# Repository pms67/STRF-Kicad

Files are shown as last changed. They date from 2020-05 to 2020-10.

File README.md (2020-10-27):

# STRF 2.4GHz RF-to-USB Dongle
STM32L4-based RF-to-USB dongle using a low-power NRF24 2.4GHz transceiver.

4-layer PCB designed in KiCad. Video: [https://www.youtube.com/watch?v=14_jh3nLSsU](https://www.youtube.com/watch?v=14_jh3nLSsU)

You can order this board (incl. SMT assembly) at [https://www.jlcpcb.com](https://www.jlcpcb.com). Gerber and assembly files are in the relevant repo folders.

STRF

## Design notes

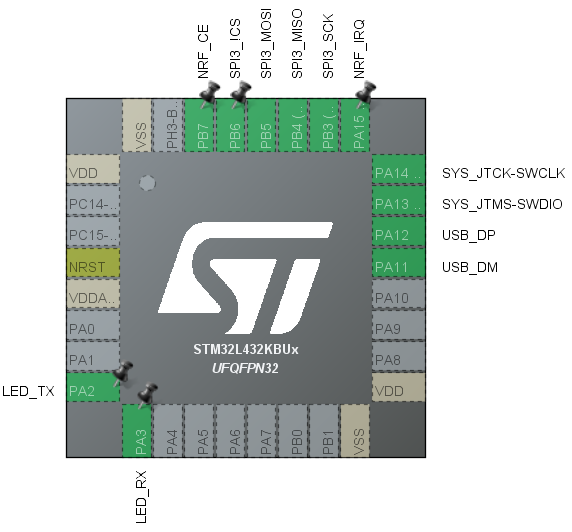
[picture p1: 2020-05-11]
misc/STM32L4 Pinout.PNG

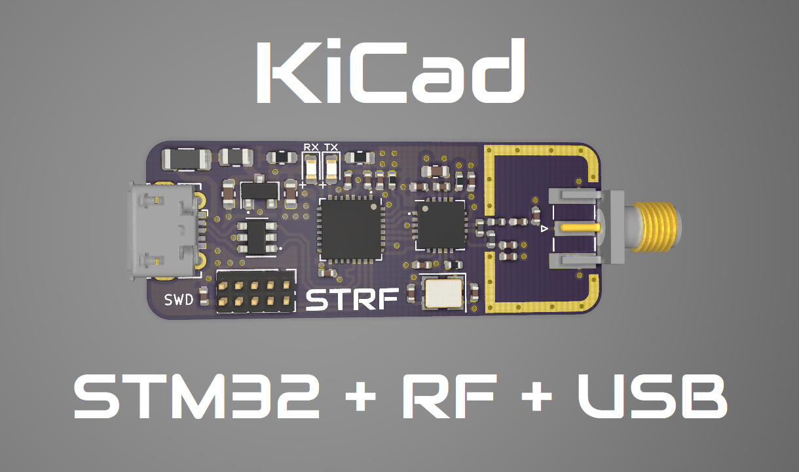
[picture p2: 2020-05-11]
misc/STRF-3D-Screenshot.png

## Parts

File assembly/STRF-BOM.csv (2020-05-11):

Designator | Quantity | Value | Footprint | LCSC Part #
C1, C2, C8, | 3 | 10u | 0603 | C19702
C3, C5, C6, C7, | 4 | 100n | 0402 | C1525
C4, | 1 | 1u | 0402 | C52923
C9, C10, C11, | 3 | 10n | 0402 | C15195
C12, | 1 | 33n | 0402 | C1585
C13, C14, | 2 | 12p | 0402 | C1547
C15, | 1 | 1p5 | 0402 | C1552
C16, | 1 | 1p | 0402 | C1550
C17, | 1 | 2n2 | 0402 | C1531
C18, | 1 | 4p7 | 0402 | C1569
D1, | 1 | GR | 0603 | C72043
D2, | 1 | YE | 0603 | C72038
F1, | 1 | 100mA | 1206
FB1, | 1 | 100 @ 100MHz | 0805 | C1015
L1, | 1 | 3n9 | 0402 | C14033
L2, | 1 | 8n2 | 0402 | C16208
L3, | 1 | 2n7 | 0402 | C27123
R1, | 1 | 10k | 0402 | C25744
R2, R3, | 2 | 2k2 | 0603 | C4190
R4, | 1 | 22k | 0402 | C25768
R5, | 1 | 1M | 0402 | C26083
U1, | 1 | XC6206P332MR | SOT-23 | C5446
U2, | 1 | USBLC6-2SC6 | SOT-23-6 | C7519
U3, | 1 | STM32L432KBU6 | UFQFPN-32_EP_5.0x5.0x0.5P | C94784
U4, | 1 | nRF24L01P | QFN-20_EP_4.0x4.0x0.5P | C8791
Y1, | 1 | 16MHz | SMD-3225_4P | C13738

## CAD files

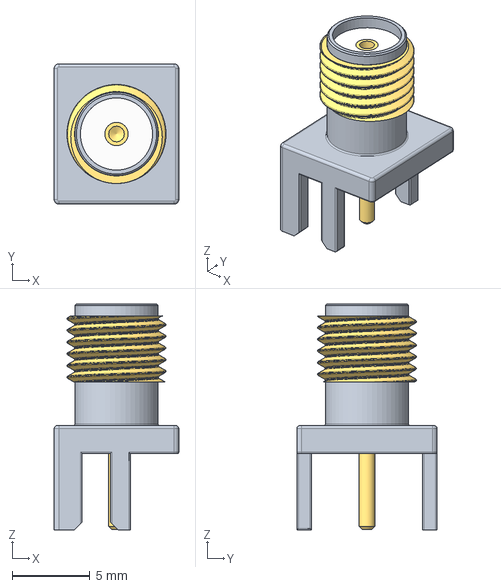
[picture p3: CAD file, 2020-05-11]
misc/SMA-20.stp
8.00 x 9.00 x 14.5 mm

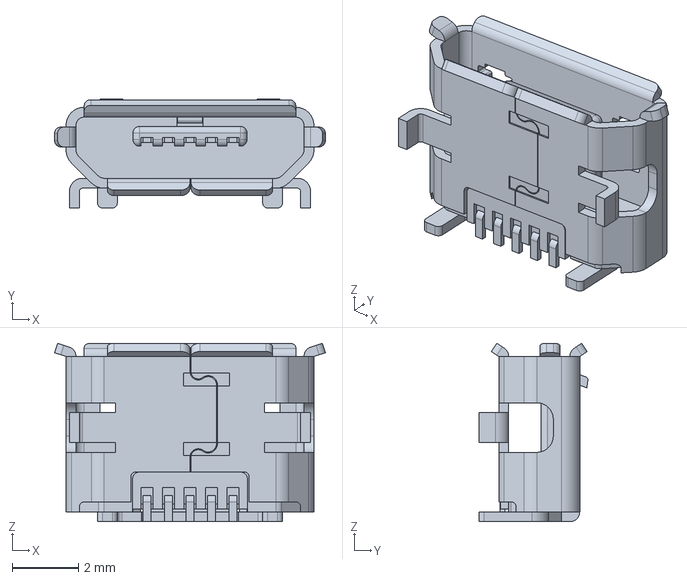
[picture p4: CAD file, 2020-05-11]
misc/1050170001.stp
8.20 x 3.30 x 5.40 mm

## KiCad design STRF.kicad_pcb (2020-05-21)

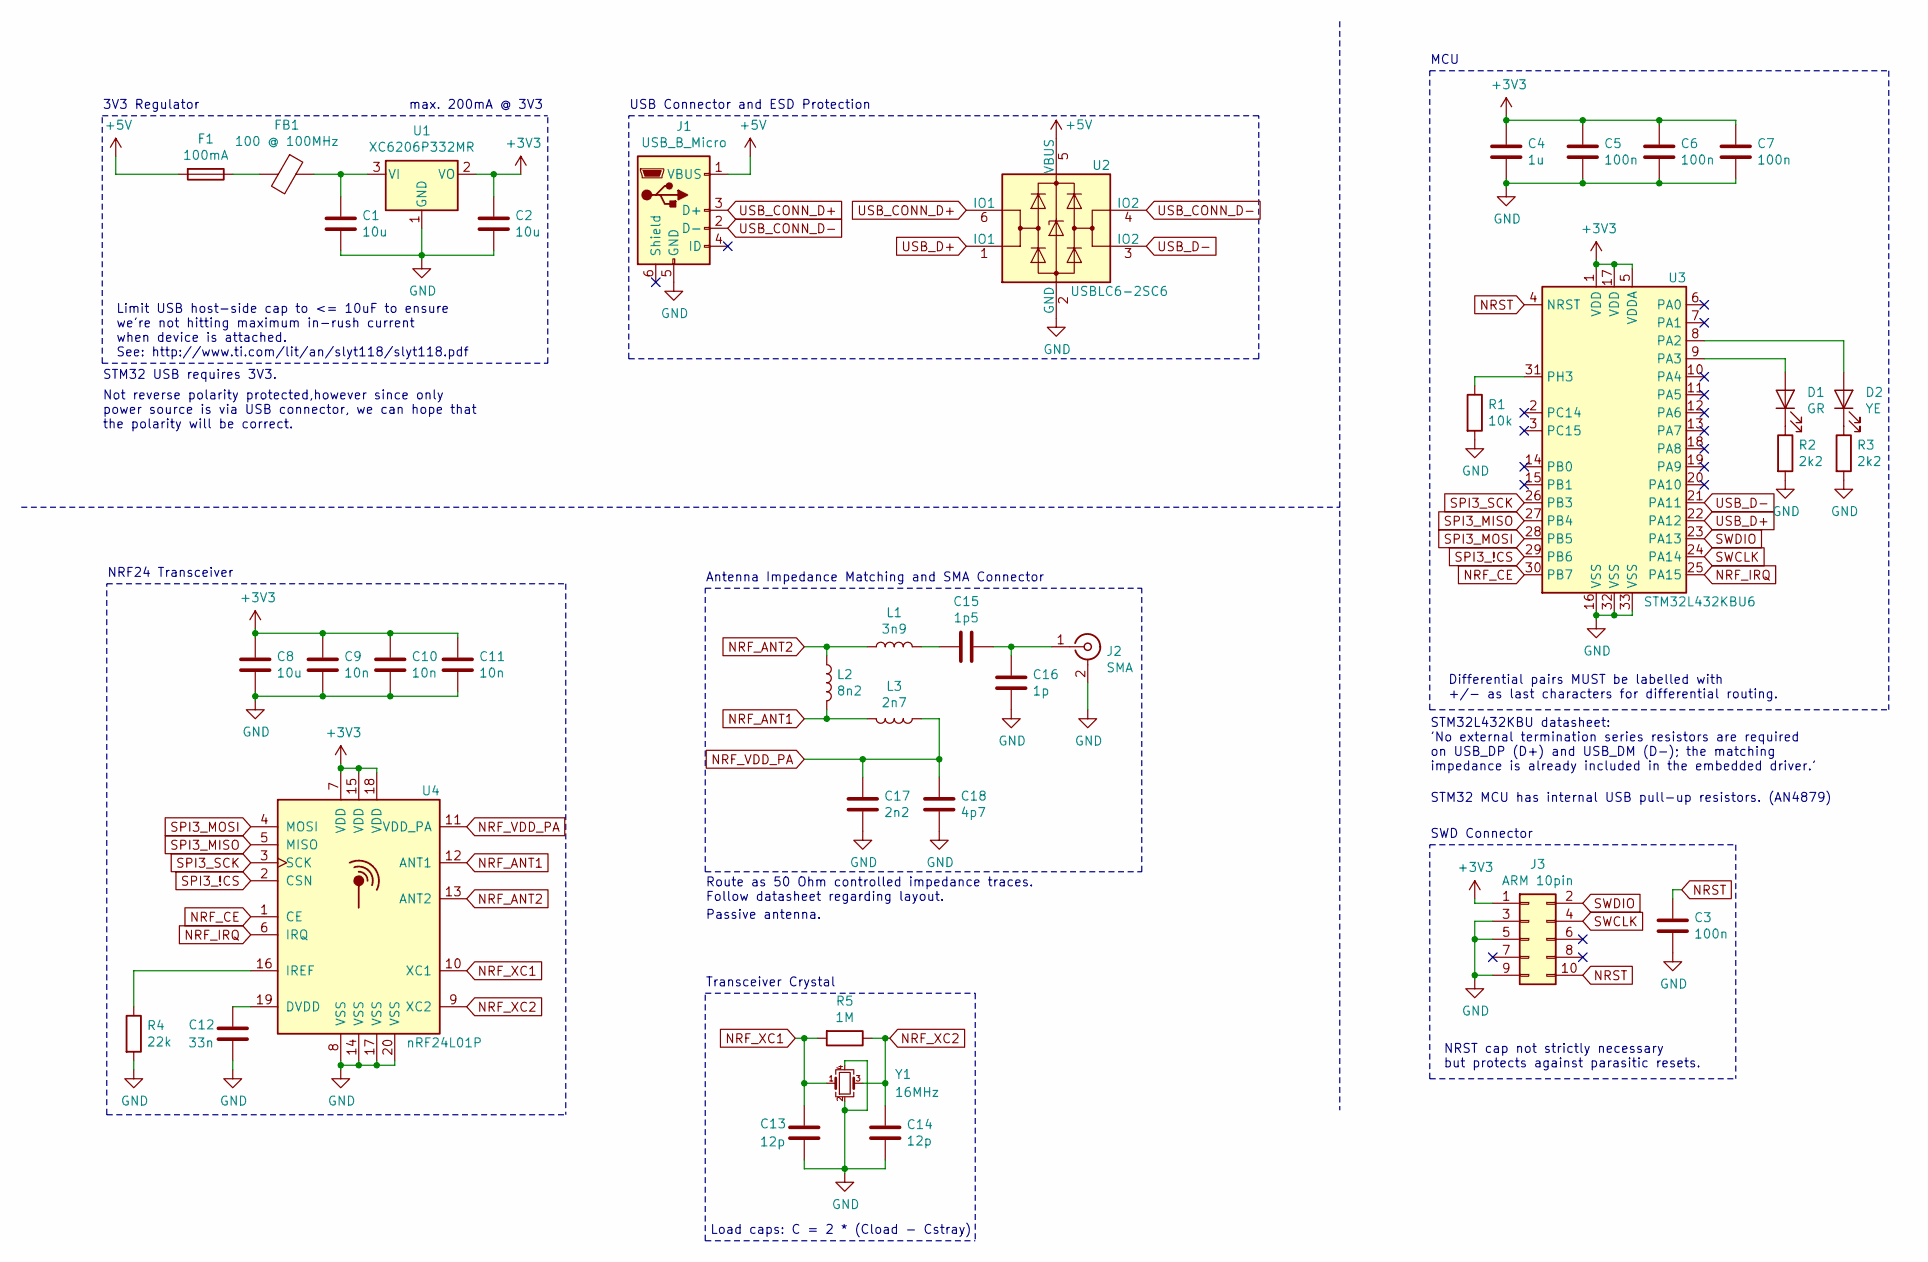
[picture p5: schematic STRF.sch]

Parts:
C1, C2, C8: 10u; C_0603_1608Metric
C3, C5, C6, C7: 100n; C_0402_1005Metric
C4: 1u; C_0402_1005Metric
C9, C10, C11: 10n; C_0402_1005Metric
C12: 33n; C_0402_1005Metric
C13, C14: 12p; C_0402_1005Metric
C15: 1p5; C_0402_1005Metric
C16: 1p; C_0402_1005Metric
C17: 2n2; C_0402_1005Metric
C18: 4p7; C_0402_1005Metric
D1: GR; LED_0603_1608Metric
D2: YE; LED_0603_1608Metric
F1: 100mA; Fuse_1206_3216Metric
FB1: 100 @ 100MHz; L_0805_2012Metric
J1: USB_B_Micro; 101181930001LF
J2: SMA; SMA_Samtec_SMA-J-P-X-ST-EM1_EdgeMount
J3: ARM 10pin; PinHeader_2x05_P1.27mm_Vertical
L1: 3n9; L_0402_1005Metric
L2: 8n2; L_0402_1005Metric
L3: 2n7; L_0402_1005Metric
R1: 10k; R_0402_1005Metric
R2, R3: 2k2; R_0603_1608Metric
R4: 22k; R_0402_1005Metric
R5: 1M; R_0402_1005Metric
U1: XC6206P332MR; SOT-23
U2: USBLC6-2SC6; SOT-23-6
U3: STM32L432KBU6; QFN-32-1EP_5x5mm_P0.5mm_EP3.45x3.45mm
U4: nRF24L01P; QFN-20-1EP_4x4mm_P0.5mm_EP2.5x2.5mm
Y1: 16MHz; Crystal_SMD_3225-4Pin_3.2x2.5mm

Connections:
+3V3: C2.1, C4.1, C5.1, C6.1, C7.1, C8.1, C9.1, C10.1, C11.1, J3.1, U1.2 (VO), U3.1 (VDD), U3.5 (VDDA), U3.17 (VDD), U4.7 (VDD), U4.15 (VDD), U4.18 (VDD)
+5V: F1.2, J1.1 (VBUS), U2.5 (VBUS)
GND: C1.2, C2.2, C3.2, C4.2, C5.2, C6.2, C7.2, C8.2, C9.2, C10.2, C11.2, C12.2, C13.2, C14.2, C16.1, C17.1, C18.1, J1.5 (GND), J2.2 (Ext), J3.3, J3.5, J3.9, R1.2, R2.2, R3.2, R4.2, U1.1 (GND), U2.2 (GND), U3.16 (VSS), U3.32 (VSS), U3.33 (VSS), U4.8 (VSS), U4.14 (VSS), U4.17 (VSS), U4.20 (VSS), U4.21, Y1.2, Y1.4
NRF_ANT1: L2.2, L3.2, U4.12 (ANT1)
NRF_ANT2: L1.1, L2.1, U4.13 (ANT2)
NRF_CE: U3.30 (PB7), U4.1 (CE)
NRF_IRQ: U3.25 (PA15), U4.6 (IRQ)
NRF_VDD_PA: C17.2, C18.2, L3.1, U4.11 (VDD_PA)
NRF_XC1: C13.1, R5.2, U4.10 (XC1), Y1.1
NRF_XC2: C14.1, R5.1, U4.9 (XC2), Y1.3
NRST: C3.1, J3.10, U3.4 (NRST)
unnamed: C1.1, FB1.1, U1.3 (VI)
unnamed: C12.1, U4.19 (DVDD)
unnamed: C15.1, C16.2, J2.1 (In)
unnamed: C15.2, L1.2
unnamed: D1.1 (K), R2.1
unnamed: D1.2 (A), U3.9 (PA3)
unnamed: D2.1 (K), R3.1
unnamed: D2.2 (A), U3.8 (PA2)
unnamed: F1.1, FB1.2
unnamed: R1.1, U3.31 (PH3)
unnamed: R4.1, U4.16 (IREF)
SPI3_!CS: U3.29 (PB6), U4.2 (CSN)
SPI3_MISO: U3.27 (PB4), U4.5 (MISO)
SPI3_MOSI: U3.28 (PB5), U4.4 (MOSI)
SPI3_SCK: U3.26 (PB3), U4.3 (SCK)
SWCLK: J3.4, U3.24 (PA14)
SWDIO: J3.2, U3.23 (PA13)
USB_CONN_D+: J1.3 (D+), U2.6 (IO1)
USB_CONN_D-: J1.2 (D-), U2.4 (IO2)
USB_D+: U2.1 (IO1), U3.22 (PA12)
USB_D-: U2.3 (IO2), U3.21 (PA11)

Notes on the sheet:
Limit USB host-side cap to <= 10uF to ensure we're not hitting maximum in-rush current when device is attached. See: http://www.ti.com/lit/an/slyt118/slyt118.pdf
NRST cap not strictly necessary but protects against parasitic resets.
Differential pairs MUST be labelled with +/- as last characters for differential routing.
3V3 Regulator
MCU
SWD Connector
STM32 MCU has internal USB pull-up resistors. (AN4879)
STM32 USB requires 3V3.
STM32L432KBU datasheet: 'No external termination series resistors are required on USB_DP (D+) and USB_DM (D-); the matching impedance is already included in the embedded driver.'
Not reverse polarity protected,however since only power source is via USB connector, we can hope that the polarity will be correct.
Load caps: C = 2 * (Cload - Cstray)
NRF24 Transceiver
Transceiver Crystal
USB Connector and ESD Protection
Antenna Impedance Matching and SMA Connector
Route as 50 Ohm controlled impedance traces. Follow datasheet regarding layout.
Passive antenna.
max. 200mA @ 3V3

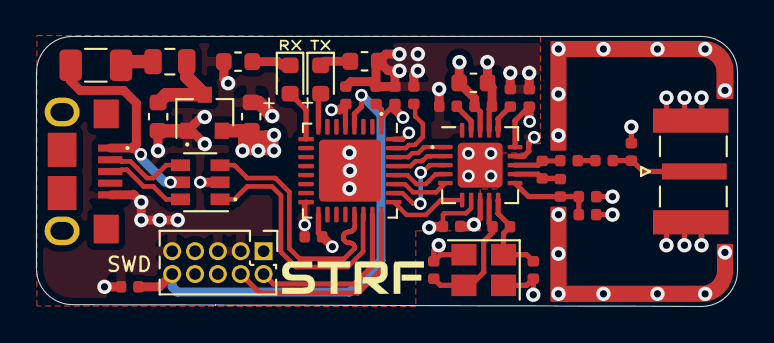
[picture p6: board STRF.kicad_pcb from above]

Board: 4 copper layers, 39.0 x 15.0 mm, 38 parts (0 on the bottom side), 32 nets.

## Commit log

2020-05-11 Initial commit.
    [1050170001.stp, SMA-20.stp, STRF-BOM.csv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]
2020-05-13 Fixed IREF resistor to pull-down.
    [STRF-BOM-Panel.csv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]
2020-05-14 Shifted SWD header further away from USB to gain space for connector.
    [STRF-B_Cu.gbr, STRF-B_Mask.gbr, STRF-B_Paste.gbr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]
2020-05-15 Updated Gerbers.
    [STRF-BOM-Panel.csv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]
2020-05-21 Increased via annular ring size, decreased SMA center pad width, added thermal vias to NRF24.
    [STRF-B_Cu.gbr, STRF-B_Mask.gbr, STRF-B_Paste.gbr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]
2020-05-21 Changed USB connector.
    [STRF-BOM.csv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]
2020-05-24 'Panelised' by hand to fit JLCPCB minimum PCB size for assembly.
    Board is 15mm in height, JLCPCB requires min. 20mm in each dimension for assembly.
    Created additional BOMs and footprint placement files for the panelised version.
    [STRF-BOM.csv, STRF_Panel-BOM.csv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]
